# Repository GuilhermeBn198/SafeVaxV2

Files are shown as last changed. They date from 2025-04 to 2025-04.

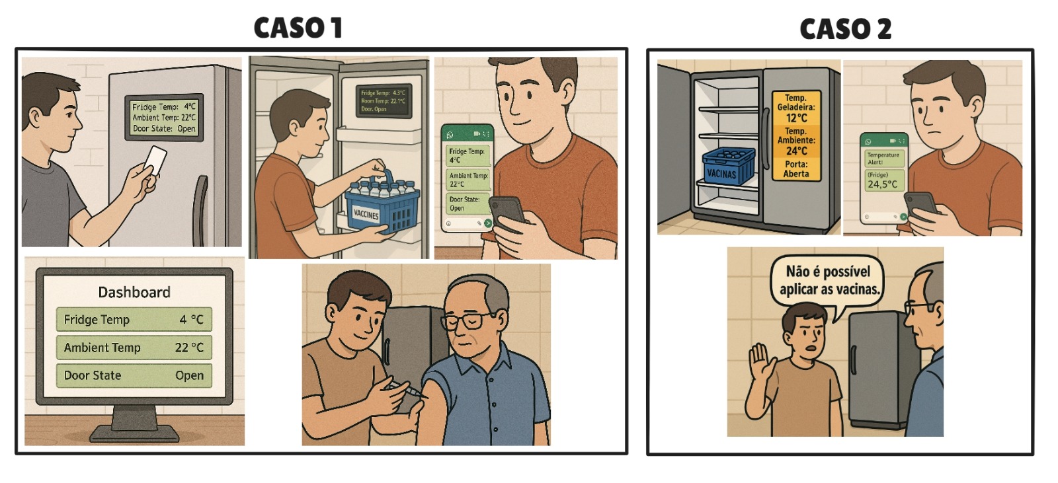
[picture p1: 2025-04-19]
Docs/Bigpicure_SafeVaxV2.jpeg

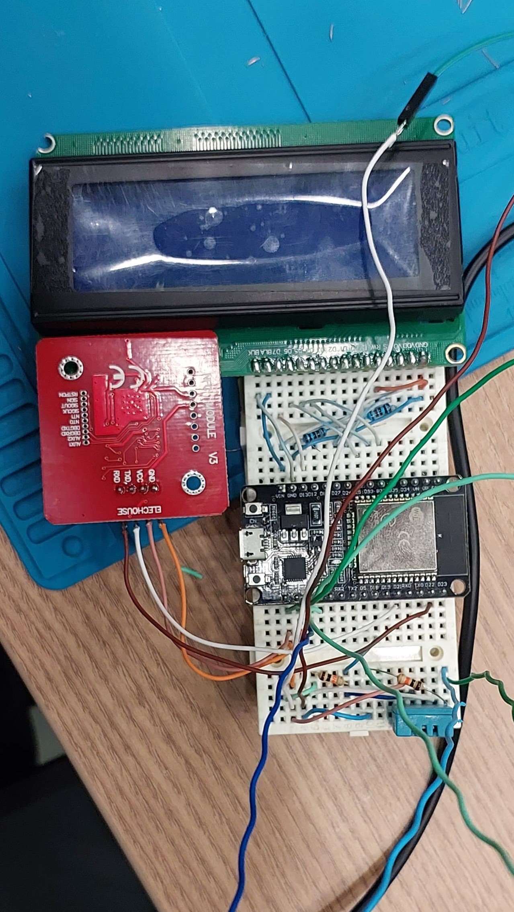
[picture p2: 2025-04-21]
Docs/imagens/prototipo pre-caixa.jpeg

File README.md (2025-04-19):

# SafeVax V2

O SafeVax é um sistema inovador voltado para o monitoramento e a segurança no armazenamento de vacinas em ambientes hospitalares. Desenvolvido para reduzir riscos e aumentar a eficiência no gerenciamento e administração de vacinas, o projeto utiliza sensores IoT (como DHT11 e RFID), compressão Huffman e criptografia AES para garantir que as condições ideais de conservação sejam sempre mantidas de forma segura e otimizada.

---

## Problema Abordado

O armazenamento adequado de vacinas é essencial para preservar sua eficácia e garantir a segurança dos pacientes. Em ambientes hospitalares, a violação das condições ideais — como a abertura frequente das portas dos refrigeradores e variações de temperatura — pode comprometer a qualidade dos insumos e, consequentemente, a saúde pública. Processos manuais de monitoramento estão sujeitos a falhas humanas, demandando uma solução automatizada, integrada e confiável.

---

## Solução Proposta

O SafeVax automatiza o monitoramento dos refrigeradores de vacinas através de:

- **Controle de Acesso:** Monitoramento da abertura e fechamento das portas do refrigerador, com registro detalhado dos acessos via sensor ultrassônico e RFID.  
- **Monitoramento de Temperatura:** Acompanhamento em tempo real da temperatura interna e externa (ambiente) com dois DHT11.  
- **Identificação via RFID:** Registro de quem acessa o refrigerador, possibilitando rastreabilidade e controle de acesso.  
- **Compressão de Dados (Huffman):** Redução do tamanho do payload JSON antes da transmissão, com árvore estática construída a partir do sampleAlphabet.  
- **Criptografia AES‑256‑CBC:** Proteção do payload comprimido usando chave de 256 bits e IV de 128 bits, garantindo confidencialidade em trânsito.  
- **Integração com Sistemas Hospitalares:** Sincronização de dados com plataformas de gestão de saúde para um monitoramento centralizado.  
- **Relatórios Automáticos & Alertas:** Geração de relatórios históricos e envio de alertas (via MQTT e WhatsApp) em caso de irregularidades.

### Melhorias e Funcionalidades Adicionais

- **Dashboard Interativo com Streamlit:** Consome as rotas HTTP do servidor Flask para visualização em tempo real e histórica.  
- **Segurança de Comunicação:**  
  - **HiveMQ TLS** para canal MQTT seguro.  
  - **AES‑256‑CBC** para criptografia de cada mensagem.  
- **Escalabilidade MQTT:** Cada ESP32 publica em `/centroDeVacinaXYZ/containerXYZ`, permitindo múltiplos containers.

---

## Credenciais e Parâmetros de Integração

| Item | Valor / Descrição |
|---|---|
| **Broker MQTT (HiveMQ)** | `cd8839ea5ec5423da3aaa6691e5183a5.s1.eu.hivemq.cloud:8883` (TLS) |
| **Username HiveMQ** | `hivemq.webclient.1734636778463` |
| **Password HiveMQ** | `EU<pO3F7x?S%wLk4#5ib` |
| **Tópico de Dados** | `/<centroDeVacinaXYZ>/<containerXYZ>` |
| **Tópico de Controle** | `esp32/control` |
| **Dicionário Huffman** | Gerado a partir do _sampleAlphabet_ (veja `PAYLOADS.md` para mapa completo `char → código binário`) |
| **Chave AES‑256 (hex)** | `A1B2C3D4E5F60718293A4B5C6D7E8F90112233445566778899AABBCCDDEEFF00` |
| **IV AES‑128 (hex)** | `00112233445566778899AABBCCDDEEFF` |

> **Nota:** em produção, o IV deve ser gerado aleatoriamente por mensagem e prefixado ao payload criptografado.

---

## Referências

- **Código-fonte ESP32:** integra DHT11 interno/externo, ultrassônico, RFID, LCD, Huffman e AES.  
- **Servidor Flask + PostgreSQL:** coleta dados MQTT, armazena em tabelas separadas (`containers` e `dados_monitoramento`).  
- **Dashboard Streamlit:** consome rotas HTTP e exibe gráficos e tabelas.  
- **PAYLOADS.md:** documentação detalhada de payload JSON, compressão e criptografia.  
  → [Veja em PAYLOADS.md](./PAYLOADS.md)

---

## Desenvolvedores

- **Guilherme Lucas Pereira Bernardo** – _Líder de Projeto & Desenvolvedor_ ~ @GuilhermeBn198
- **Vinícius Brito** – _Especialista em Hardware_ ~ @ViniKhael  
- **Ruan Oliveira** – _Desenvolvedor de Software e Especialista em Saúde_ ~ @rouancb  
- **Gabriel Guilherme** – _Engenheiro de Dados_ ~ @Bounded-Bytes  

Para contribuir ou entrar em contato, consulte as informações no repositório.

---

SafeVax V2 é um passo importante rumo a um sistema de armazenamento de vacinas mais seguro, eficiente e confiável, promovendo a saúde pública e a excelência na gestão hospitalar.

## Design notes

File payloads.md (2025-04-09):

# SafeVax ESP32 — Payloads, Compressão e Criptografia

## 1. Estrutura do Payload JSON

Cada mensagem, antes de compressão e criptografia, tem o formato:

```json
{
  "temperatura_interna": 7.25,
  "umidade_interna": 45.80,
  "temperatura_externa": 26.10,
  "umidade_externa": 55.20,
  "estado_porta": "Fechada",
  "usuario": "ab12cd34",
  "alarm_state": "OK",
  "motivo": "periodic"
}
```

## 2. Compressão Huffman

1. **Árvore estática**: gerada a partir do `sampleAlphabet`.
2. **Mapeamento**: cada caractere → código binário (ex.: `{`→`1010`, `}`→`1101`, etc.).
3. **Compressão**: substitui cada caractere pelo seu código.

```cpp
String compressed = huffmanCompress(jsonString);
```

## 3. Criptografia AES-256-CBC

1. **Pad PKCS#7** para múltiplos de 16 bytes.  
2. **Encriptação** com chave de 256 bits e IV de 128 bits:

   ```cpp
   String cipher = aes_encrypt_b64(compressed);
   ```

3. **Envio**: `client.publish(topic, cipher.c_str());`

## 4. Descriptografia e Descompressão

No ESP32 (callback) ou em outro AP:

1. **Base64 → bytes**  
2. **AES-256-CBC decrypt** → padded compressed  
3. **Remove pad** → compressed  
4. **Huffman decompress** → JSON original  

   ```cpp
   String decrypted = aes_decrypt_b64(cipherText);
   String json = huffmanDecompress(decrypted, huffmanTree);
   ```

## 5. Exemplo Completo

```text
JSON → Huffman → AES → Base64  → MQTT
          ↑             ↑
      Descomprime  Descriptografa
```

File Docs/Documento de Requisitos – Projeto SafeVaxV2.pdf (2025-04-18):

Documento de Requisitos – Projeto SafeVax V2

Introdução

O projeto SafeVax V2 tem como objetivo oferecer uma solução automatizada, segura e escalável para o monitoramento e a proteção no armazenamento de vacinas em ambientes hospitalares. Utilizando dispositivos IoT e uma arquitetura distribuída, o sistema garante que as condições ideais de conservação sejam mantidas, contribuindo para a segurança dos pacientes e a eficiência dos processos de gerenciamento.

Escopo

O sistema SafeVax V2 abrange as seguintes funcionalidades:

- Monitoramento em Tempo Real:
- Coleta de dados de temperatura e estado dos freezers por meio de sensores (ex.: DHT11 e sensores de abertura/fechamento de portas).
- Registro e Controle de Acessos:
- Registro dos acessos através de tecnologia RFID.
- Integração e Comunicação:
- Envio dos dados coletados, criptografados e compactados (usando Huffman), para um broker MQTT.
- Estruturação de tópicos MQTT que possibilitam a identificação individual de cada freezer e seus sensores.
- Processamento Centralizado:
- Um servidor Flask capta as informações do broker MQTT, descompacta e descriptografa os dados e os registra em um banco de dados PostgreSQL.
- O servidor Flask expõe os dados via API HTTP para consumo por outros módulos.
- Visualização e Notificações:
- Um dashboard interativo, desenvolvido com Streamlit, se conecta à API do servidor Flask para gerar gráficos, tabelas e relatórios históricos.

- Notificações de alerta no WhatsApp quando o acesso for “NÃO AUTORIZADO” e quando a temperatura for maior que a indicada pela OMS. (Entre 2º e 8º C)

Objetivos

- Garantir a eficácia das vacinas:
- Monitorar e manter as condições ideais de armazenamento por meio de medições precisas e automáticas.
- Melhorar a segurança:
- Registrar os acessos e identificar os responsáveis pela abertura dos refrigeradores utilizando RFID.
- Automatizar a gestão:
- Reduzir a dependência de processos manuais e minimizar erros humanos, utilizando comunicação via MQTT e processamento centralizado.
- Facilitar a análise dos dados:
- Disponibilizar informações de forma clara e interativa por meio de dashboards (Streamlit) e relatórios históricos.
- Assegurar a integridade e a segurança dos dados:
- Aplicar algoritmos de compactação (Huffman) e criptografia robusta em todas as etapas da comunicação entre os dispositivos IoT, o servidor e as interfaces de visualização e alerta.

Requisitos Funcionais

Monitoramento e Controle

- RF1: O sistema deverá monitorar a temperatura interna dos refrigeradores em tempo real utilizando o sensor DHT11.
- RF2: O sistema deverá registrar o estado (aberto/fechado) da porta dos containers através de um sensor de ultrassônico HC-SR04. O sensor ficará fixado na parte superior do container, voltado para a parte móvel da porta. Ao detectar uma alteração de distância – que indica a abertura ou fechamento da porta – o sensor informará o sistema imediatamente. Além disso, se a porta for aberta e não for identificada a presença de um cartão RFID dentro de 10 segundos, o sistema deverá emitir um alerta.

- RF3: O sistema deverá identificar e registrar os usuários que acessam os freezers utilizando tecnologia RFID.

Integração e Comunicação

- RF5: O sistema deverá enviar os dados coletados, devidamente criptografados e compactados (usando o algoritmo de Huffman), para um broker MQTT.
- RF6: O sistema deverá utilizar uma estrutura de tópicos MQTT para identificar individualmente cada freezer e seus respectivos sensores.
- RF7: Um servidor Flask deverá captar os dados enviados via MQTT, descompactá-los e descriptografá-los, registrando as informações em um banco de dados SQLite.
- RF8: O servidor Flask deverá disponibilizar os dados processados via API HTTP para consumo por outras interfaces do sistema.

Alertas e Notificações

- RF9: O sistema deverá enviar notificações automáticas via WhatsApp aos gestores em casos de irregularidades.

Visualização de Dados

- RF11: Um dashboard interativo, utilizando a ferramenta Streamlit, deverá ser disponibilizado para a visualização dos dados coletados de forma clara e legível.
- RF12: O dashboard deverá apresentar gráficos, tabelas e relatórios históricos para auxiliar na análise e tomada de decisões.

Requisitos Não Funcionais

Performance

- RNF1: O sistema deverá realizar a coleta e transmissão dos dados com baixa latência, garantindo atualizações em tempo real.
- RNF2: A compactação dos dados deverá reduzir significativamente o volume de informações transmitidas, sem comprometer a integridade dos dados.

Segurança

- RNF3: A comunicação entre os dispositivos IoT, o broker MQTT, o servidor Flask deverá ser protegida por criptografia robusta.
- RNF4: O acesso ao dashboard e aos dados deverá ser controlado por autenticação e autorização.

Usabilidade

- RNF5: O dashboard desenvolvido em Streamlit deverá oferecer uma experiência de usuário clara, com design responsivo.

Escalabilidade e Manutenção

- RNF6: A arquitetura do sistema deverá ser modular e escalável.
- RNF7: O código deverá ser documentado e seguir boas práticas de desenvolvimento.

Requisitos de Integração e Melhoria

- RM1: Implementar algoritmos de compactação de dados (mínimo dois), utilizando o algoritmo de Huffman.
- RM2: Implementar um algoritmo de criptografia robusto.
- RM3: Desenvolver um dashboard interativo utilizando Streamlit.
- RM4: Implementar um mecanismo de cadastro e gerenciamento de múltiplos freezers, utilizando tópicos MQTT estruturados.

Considerações Finais

O projeto SafeVax V2 visa transformar o monitoramento e a segurança no armazenamento de vacinas em ambientes hospitalares através de uma abordagem integrada que alta tecnologia IoT, segurança de dados e interfaces amigáveis para o usuário. Este documento de requisitos servirá de base para o desenvolvimento e a validação do sistema, garantindo que todas as funcionalidades essenciais e melhorias sejam implementadas de acordo com as necessidades dos stakeholders e as melhores práticas de engenharia.

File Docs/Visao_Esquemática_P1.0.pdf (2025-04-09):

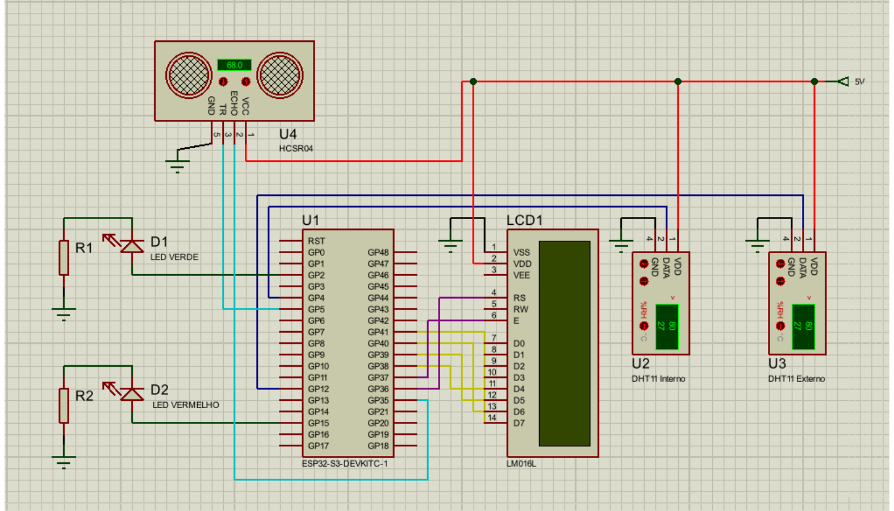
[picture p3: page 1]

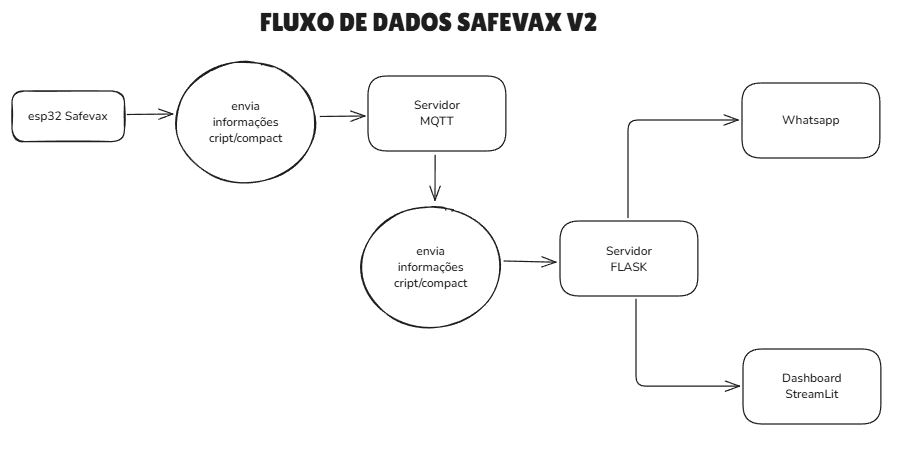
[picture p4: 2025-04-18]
Docs/Fluxo_de_Dados_SafeVaxV2.jpeg

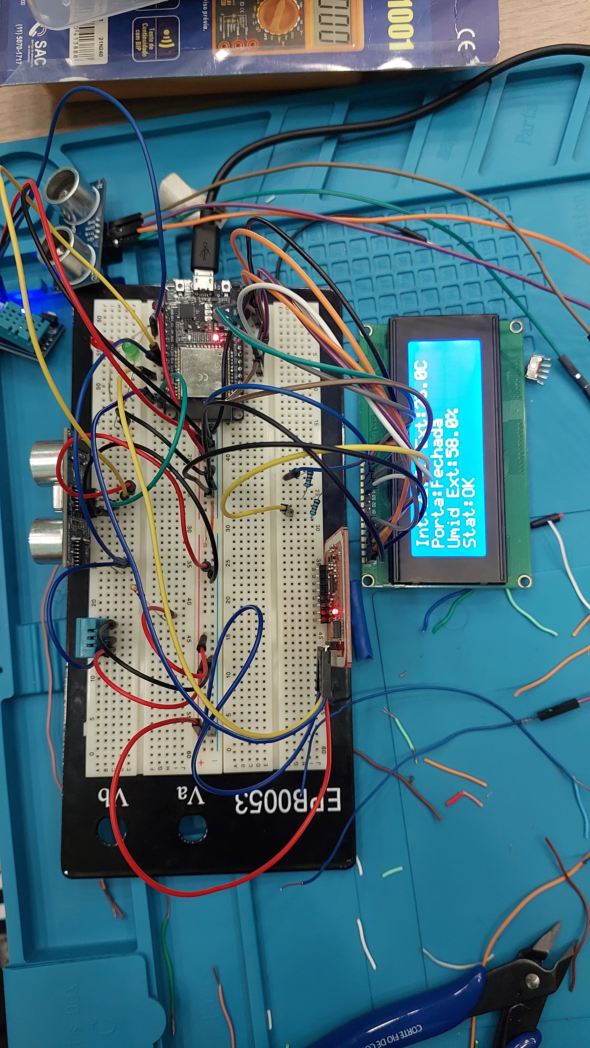
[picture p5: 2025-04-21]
Docs/imagens/prototipo 1.jpeg

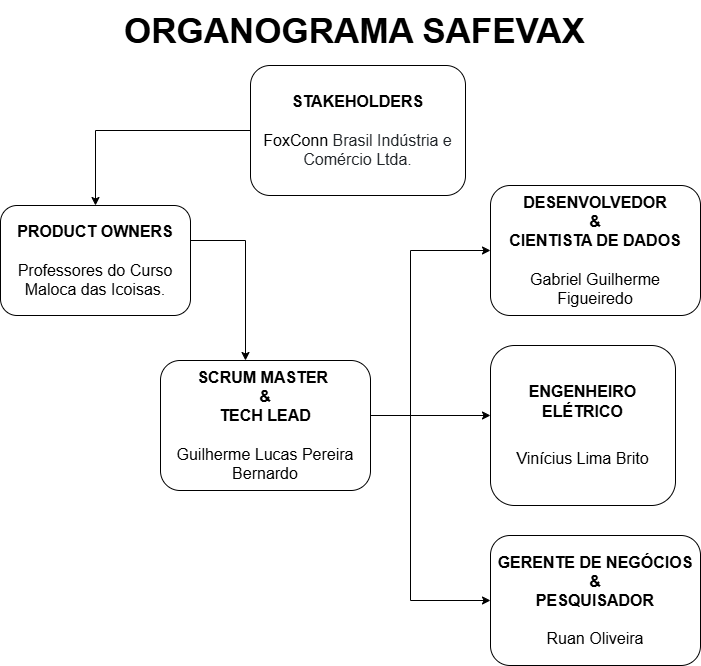
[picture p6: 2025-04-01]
Docs/Organograma-SafeVaxV2.drawio.png

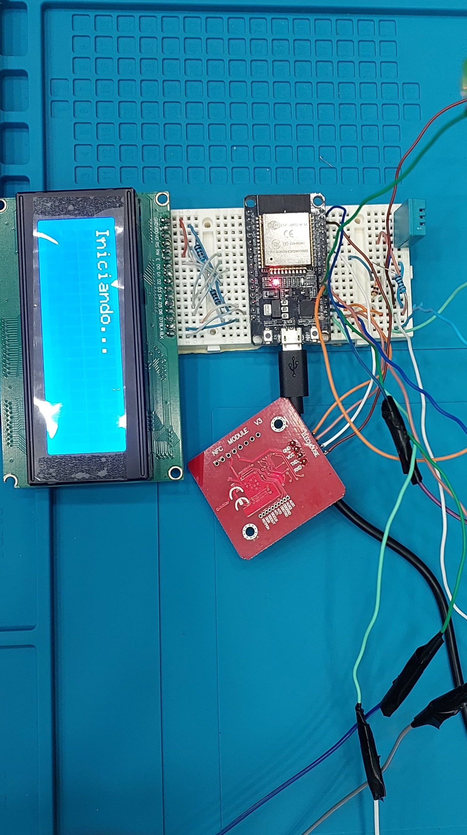
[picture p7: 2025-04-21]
Docs/imagens/prototipo pre-caixa-2.jpeg

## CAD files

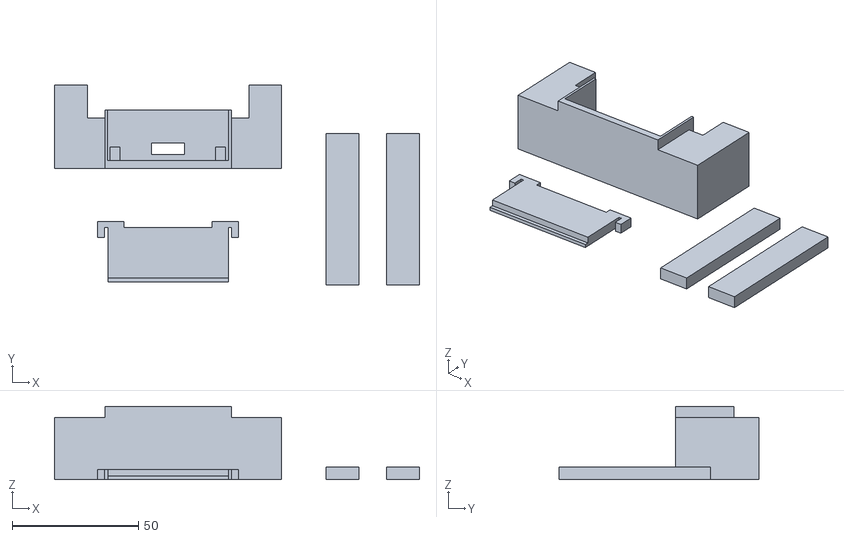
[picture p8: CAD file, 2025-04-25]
3d_printing/Sensor-ultrassonico_Safevax_imprimir.stl
144.6 x 79.3 x 29.0

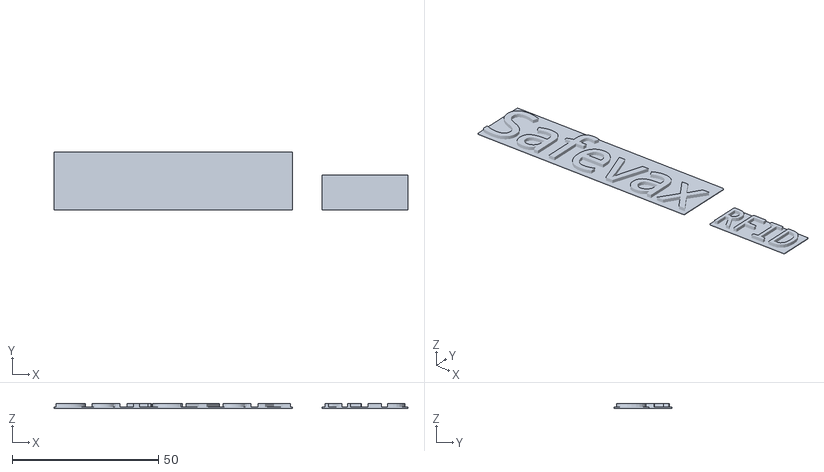
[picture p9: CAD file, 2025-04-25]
3d_printing/Letras_Caixa_imprimir.stl
121.2 x 20.0 x 1.60

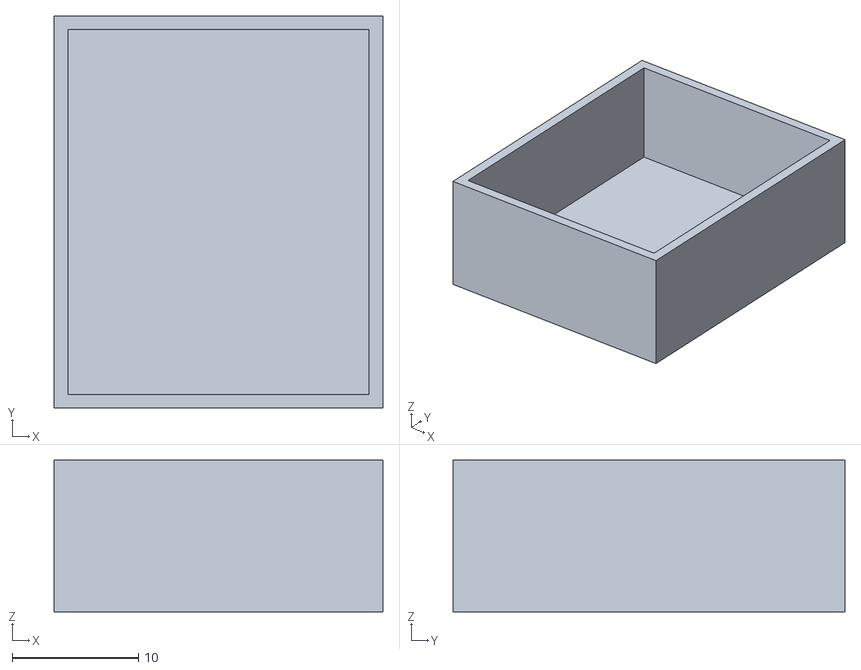
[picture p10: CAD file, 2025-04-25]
3d_printing/DHT_Interno_imprimir.stl
26.0 x 31.0 x 12.0

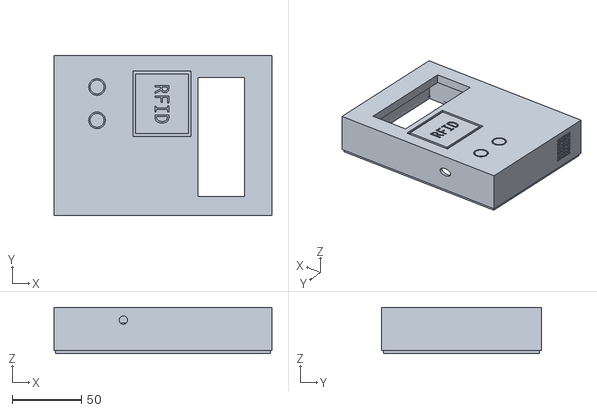
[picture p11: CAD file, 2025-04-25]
3d_printing/Topo_Safevax_imprimir.stl
157.0 x 115.0 x 33.4

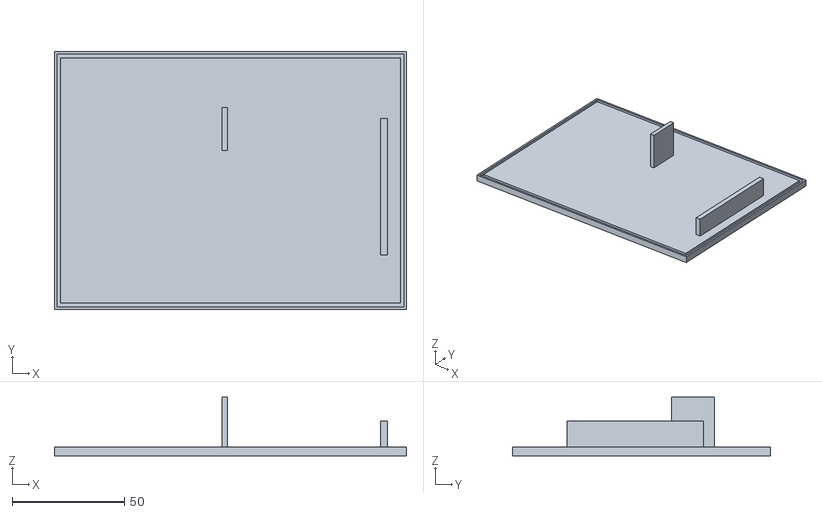
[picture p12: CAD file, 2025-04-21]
3d_printing/Base_Safevax_imprimir.stl
157.0 x 115.0 x 26.2

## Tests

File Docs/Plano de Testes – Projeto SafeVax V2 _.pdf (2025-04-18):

Plano de Testes – Projeto SafeVax V2

### 1. Introdução

Este documento descreve o plano de testes para o projeto SafeVax V2, visando validar que o sistema atende aos requisitos funcionais, não funcionais e de integração. O objetivo é garantir que todas as funcionalidades – desde a coleta e transmissão dos dados dos freezers até a visualização e notificação – operem de forma segura, eficiente e integrada.

### 2. Objetivos dos Testes

- Verificação Funcional: Garantir que cada requisito funcional seja implementado corretamente e opere conforme esperado.
- Validação da Integração: Assegurar que os diferentes módulos do sistema (dispositivos IoT, broker MQTT, servidor Flask, banco de dados, dashboard Streamlit) se comuniquem e interajam corretamente.
- Avaliação da Segurança e Desempenho: Testar a eficácia dos algoritmos de compactação (Huffman) e criptografia, bem como a latência na transmissão dos dados.
- Testes de Usabilidade: Verificar a interface e a experiência do usuário no dashboard interativo em Streamlit e com as notificações.
- Testes Manuais e Unitários: Enquanto os módulos do ESP32 serão validados via testes manuais in loco, os testes unitários serão aplicados no Streamlit.

### 3. Escopo dos Testes

3.1 - Componentes a Serem Testados

- Dispositivos IoT e Comunicação via MQTT:
- Sensores de temperatura (DHT11).
- Sensores de estado da porta do container, utilizando sensor de luz infravermelho PIR, instalado na parte superior do container e voltado para a parte móvel da porta.
- Módulo RFID para identificação de acessos.
- Envio dos dados (compactados e criptografados) via MQTT.

- Servidor Flask e Integração com Banco de Dados:
- Captação dos dados via MQTT.
- Processamento: descompactação (Huffman), descriptografia e registro dos dados em banco (SQLite ou PostgreSQL, conforme a versão adotada).
- Exposição dos dados via API HTTP.
- Interface de Visualização e Notificações:
- Dashboard interativo desenvolvido com Streamlit.
- Notificações no WhatsApp para recebimento dos dados, emissão de alertas.

Componentes Excluídos dos Testes

- Testes unitários e de integração não serão aplicados aos módulos do ESP32, que serão validados via testes manuais in loco.

### 4. Estratégia de Testes

4.1 - Tipos de Testes

- Testes Funcionais (Manuais):
- Funcionamento dos sensores (temperatura e sensor PIR para estado da porta).
- Leitura e registro dos acessos via RFID.
- Envio e recepção dos dados via MQTT.
- Processamento no servidor Flask (descompactação, descriptografia e registro dos dados).
- Testes de Integração (Manuais):
- Dispositivos IoT → Broker MQTT → Servidor Flask → API HTTP.
- Integração entre o servidor e o dashboard (Streamlit).
- Testes Unitários (Automatizados):

- Módulos do dashboard em Streamlit:

■ Validação dos métodos de descriptografia e descompactação. ■ Verificação da lógica de exibição e manipulação de dados.
■ Testes de notificação e alerta no WhatsApp.
- Testes de Segurança:
- Robustez da criptografia aplicada e integridade dos dados durante a transmissão.
- Testes de Performance:
- Medir a latência na transmissão dos dados e a eficácia da compactação, garantindo comunicação em tempo real com baixa latência.

4.2 - Ferramentas de Teste

- Ambiente de Teste Manual:
- Equipamentos com ESP32, sensores (DHT11 e sensor PIR), módulo RFID e broker MQTT configurado.
- Ambiente de Teste Automatizado:
- Frameworks de testes para Streamlit (Python unittest/pytest).
- Ferramentas de Monitoramento:
- Logs e analisadores de pacotes (ex.: Wireshark) para validar a criptografia e a integridade dos dados.

### 5. Casos de Teste

5.1 - Testes Funcionais

- TF-01: Monitoramento de Temperatura
- Objetivo: Verificar se o sensor DHT11 coleta e envia a temperatura em tempo real.
- Procedimento:

1. Simular variações de temperatura no ambiente do freezer.
2. Verificar a exibição dos dados enviados via MQTT.
- Resultado Esperado: Dados precisos e atualizados em tempo real.
- TF-02: Registro de Estado da Porta do Container
- Objetivo: Confirmar que o sensor de luz infravermelho PIR registra corretamente o estado (aberto/fechado) da porta do container.
- Procedimento:
1. Simular a abertura e fechamento da porta do container.
2. Observar se o sensor PIR detecta a alteração de estado imediatamente e se essa informação é enviada ao sistema.
- Resultado Esperado: Cada mudança de estado é registrada e transmitida instantaneamente.
- TF-03: Emissão de Alerta por Ausência de RFID
- Objetivo: Validar que, ao abrir a porta do container, se nenhum cartão RFID for identificado em até 10 segundos, o sistema emite um alerta.
- Procedimento:
1. Abrir a porta do container.
2. Não apresentar nenhum cartão RFID ao leitor durante 10 segundos.
3. Verificar se o sistema emite o alerta conforme especificado.
- Resultado Esperado: Alerta emitido imediatamente após o período de 10 segundos sem identificação de RFID.
- TF-04: Identificação via RFID
- Objetivo: Validar o registro de acesso dos usuários por meio do RFID.
- Procedimento:

1. Aproximar um cartão RFID do leitor.
2. Verificar se o acesso é registrado com os dados corretos.
- Resultado Esperado: A identificação do usuário é capturada e enviada corretamente.
- TF-05: Envio de Dados via MQTT
- Objetivo: Confirmar que os dados são compactados, criptografados e enviados ao broker MQTT.
- Procedimento:
1. Verificar os dados enviados a partir dos freezers utilizando um analisador de pacotes.
- Resultado Esperado: Dados enviados no formato esperado, compactados e criptografados.

### 5.2 Testes de Integração

- TI-01: Integração do Servidor Flask
- Objetivo: Verificar a recepção dos dados pelo servidor Flask e seu processamento (descompactação e descriptografia).
- Procedimento:
1. Enviar dados via MQTT a partir dos dispositivos.
2. Confirmar que o servidor Flask processa e armazena os dados no banco.
- Resultado Esperado: Dados corretamente registrados e disponíveis via API HTTP.
- TI-02: Integração do Dashboard (Streamlit)
- Objetivo: Validar a exibição dos dados no dashboard interativo.
- Procedimento:
1. Conectar o dashboard à API do servidor Flask.

2. Verificar a atualização em tempo real dos gráficos e tabelas.
- Resultado Esperado: Dados apresentados de forma clara e interativa.
- TI-03: Integração das notificações
- Objetivo: Testar o consumo dos dados (criptografados e compactados) e o envio de alertas.
- Procedimento:
1. Simular condições críticas (ex.: temperatura elevada ou porta aberta sem RFID).
2. Verificar a recepção dos dados no WhatsApp e a emissão dos alertas.
- Resultado Esperado: Notificações enviadas corretamente aos gestores.

### 5.3 Testes de Segurança

- TS-01: Validação da Criptografia
- Objetivo: Confirmar que os dados são criptografados durante a transmissão.
- Procedimento:
1. Utilizar ferramentas de análise de pacotes para interceptar a comunicação.
2. Verificar se os dados estão protegidos.
- Resultado Esperado: Nenhum dado em texto claro é visível.
- TS-02: Teste de Integridade dos Dados
- Objetivo: Verificar se os dados mantêm sua integridade após a compactação e descompactação.
- Procedimento:
1. Comparar os dados antes e depois do processo.
- Resultado Esperado: Os dados permanecem íntegros e sem perdas.

### 5.4 Testes de Performance

- TP-01: Latência na Transmissão
- Objetivo: Medir o tempo entre a coleta dos dados e sua disponibilidade via API.
- Procedimento:
1. Realizar medições em diferentes condições de rede.
- Resultado Esperado: Latência dentro dos parâmetros estabelecidos para atualizações em tempo real.

### 5.5 Testes Unitários (Criptografia e Streamlit)

- TU-01: Testes de Descriptografia e Descompactação
- Objetivo: Validar as funções de descriptografia e descompactação dos dados.
- Procedimento:
1. Executar testes automatizados utilizando o framework de testes.
- Resultado Esperado: Funções retornam os dados corretamente processados.
- TU-02: Testes dos Componentes do Dashboard (Streamlit)
- Objetivo: Verificar que os componentes do dashboard (gráficos, tabelas, etc.) processam e exibem os dados conforme esperado.
- Procedimento:
1. Utilizar pytest ou outro framework para testar os componentes.
- Resultado Esperado: Componentes apresentam os dados de forma correta e responsiva.

### 6. Cronograma e Ambiente de Teste

- Ambiente de Teste Manual:

- Equipamentos com ESP32, sensores (DHT11 e PIR), módulo RFID e freezers em ambiente controlado.
- Broker MQTT configurado para simulação do fluxo completo.
- Ambiente de Teste Automatizado:
- Configuração de testes unitários para o Streamlit em ambiente de desenvolvimento.
- Cronograma:
- Testes Funcionais e de Integração: Durante a implementação e após a integração de cada módulo.
- Testes Unitários: Após a implementação dos módulos críticos no Streamlit.
- Testes de Performance e Segurança: Durante a fase de integração e antes da implantação final.

### 7. Critérios de Aceitação

- Funcionalidade: Todos os requisitos funcionais e de integração (incluindo os novos testes para o sensor PIR e a verificação do alerta por ausência de RFID) devem ser atendidos conforme os resultados dos testes.
- Segurança: A comunicação deve estar criptografada e os dados devem manter sua integridade durante os processos de compactação/descompactação.
- Performance: A latência do sistema deve permitir atualizações em tempo real.
- Usabilidade: As interfaces das notificações e do dashboard devem ser intuitivas e responsivas, garantindo uma boa experiência ao usuário.

### 8. Conclusão

Este plano de testes tem o intuito de assegurar que o projeto SafeVax V2 opere de forma integrada, segura e eficiente, cumprindo todos os requisitos definidos – incluindo a nova abordagem para o monitoramento do estado da porta do container via sensor PIR e a emissão de alertas na ausência de identificação RFID dentro de 10 segundos. As etapas de testes manuais, unitários e de integração garantirão a qualidade e robustez do sistema antes da implantação em ambiente real. Este documento será atualizado conforme novas funcionalidades e requisitos forem incorporados ao projeto.

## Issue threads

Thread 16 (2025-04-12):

História 10: Desenvolver a apresentação do SafeVax V2

ViniKhael, 2025-04-12:
Objetivo: confeccionar slides para apresentação final

ViniKhael, 2025-04-12:
link para edição

[slides](https://www.canva.com/design/DAGkXQlZIMw/yxwt_RUENYFcpbU0UVuHzg/edit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)

ViniKhael, 2025-04-25:
finalizado com ultimo commit da task sendo

> Commit 7535cfe

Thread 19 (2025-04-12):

História 4: Desenvolvimento do Aplicativo Mobile em Flutter

GuilhermeBn198, 2025-04-12:
Objetivo: Criar um aplicativo mobile que consome os dados do servidor MQTT (ou da API do Flask) e exibe alertas e notificações em tempo real.

- [ ] Task 4.1: Criar a estrutura inicial do aplicativo em Flutter.

- [ ] Task 4.2: Implementar a conexão com o servidor MQTT ou com a API HTTP para receber dados.

- [ ] Task 4.3: Desenvolver a funcionalidade para descriptografar e descompactar os dados recebidos.

- [ ] Task 4.4: Implementar notificações e alertas baseados nos dados críticos (ex.: temperatura acima do limite).

- [ ] Task 4.5: Desenvolver e executar testes unitários nos módulos críticos do aplicativo.

GuilhermeBn198, 2025-04-12:
Decidimos por encerrar o desenvolvimento do aplicativo e passar a gerar notificações diretamente pelo servidor Flask, através de sms, whatsapp api ou EMAIL

Closed 2025-04-12.

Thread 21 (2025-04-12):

História 6: Cadastro e Gerenciamento de Múltiplos Freezers

GuilhermeBn198, 2025-04-12:
Objetivo: Desenvolver e implementar a estratégia para cadastrar e gerenciar múltiplos freezers, utilizando tópicos MQTT e mensagens retidas.

- [ ] Task 6.1: Definir e implementar a estrutura dos tópicos MQTT para freezers e sensores.

- [ ] Task 6.2: Criar um mecanismo de cadastro (por exemplo, utilizando mensagens MQTT retidas ou um arquivo de configuração) para registrar os freezers e seus sensores.

- [ ] Task 6.3: Implementar a lógica no ESP32 para associar cada sensor a um freezer específico.

- [ ] Task 6.4: Validar a integração e a distinção dos dados entre os freezers através de testes manuais.

- [ ] Task 6.5: Atualizar a documentação com o novo fluxo de cadastro e gerenciamento de freezers.

ViniKhael, 2025-04-25:
fechado com ultimo commit relacionado ao assunto:

> sendo Commit 41b83aa

> Dashboard finalizado podendo utilizar dados de diferentes freezers [https://safevaxv2-e3nuk9n9uzugpcmk6w2gep.streamlit.app/](Dashboard Safevax V2)

Closed 2025-04-25.

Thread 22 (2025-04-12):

História 3: Desenvolvimento do Servidor Flask e Integração com Banco SQLite

GuilhermeBn198, 2025-04-12:
Objetivo: Criar um servidor Flask que capta dados do MQTT, descompacta e descriptografa as informações e as registra em um banco SQLite.

- [x] Task 3.1: Desenvolver o servidor Flask para se conectar ao broker MQTT e receber os dados.

- [x] Task 3.2: Implementar a lógica para descompactar (Huffman) e descriptografar os dados recebidos.

- [x] Task 3.3: Registrar os dados processados em um banco de dados SQLite.

- [x] Task 3.4: Expor uma API HTTP que disponibilize os dados criptografados e compactados para o consumo pelo Streamlit e Flutter.

ViniKhael, 2025-04-25:
História finalizada sendo o ultimo commit relacionado:

> Commit 98f3260

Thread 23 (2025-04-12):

História 5: Desenvolvimento do Dashboard Interativo com Streamlit

GuilhermeBn198, 2025-04-12:
Objetivo: Criar um dashboard interativo que consome dados da API do Flask e apresenta gráficos e relatórios para análise.

- [x] Task 5.1: Criar o layout básico do dashboard utilizando Streamlit.

- [ ] Task 5.2: Implementar a conexão com a API do Flask para receber os dados.

- [x] Task 5.3: Desenvolver gráficos, tabelas e relatórios que apresentem os dados de forma clara.

- [x] Task 5.4: Desenvolver e executar testes unitários para os componentes do dashboard.

ViniKhael, 2025-04-25:
história fechada com ultimo commit relacionado sendo:

> Commit 41b83aa

Closed 2025-04-25.

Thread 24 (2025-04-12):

História 7: Projeto de Modelagem 3D e Layout do Hardware

GuilhermeBn198, 2025-04-12:
**Objetivo:** Definir e implementar a disposição física dos dispositivos e eletrônicos no freezer de vacinas, utilizando uma impressora 3D para a criação de suportes e peças customizadas que garantam a integridade dos componentes e a eficiência do monitoramento.

### Abordagem e Considerações Técnicas
**ESP32:**
Recomenda-se que o ESP32 seja posicionado fora do freezer. Essa localização evita problemas relacionados à umidade e condensação, além de facilitar a manutenção e o acesso para eventuais atualizações.

**Sensor DHT11:**
O sensor deve estar localizado dentro do freezer para medir com precisão a temperatura interna. Entretanto, ele pode ser fixado em um suporte impresso em 3D que garanta sua estabilidade e a proteção contra impactos, sem interferir na circulação do ar.

**Módulo RFID:**
O módulo de RFID pode ser posicionado junto ao ESP32, fora do freezer, ou em uma área de interface com o usuário (próximo à porta) onde o cartão possa ser lido sem expor o sensor a condições adversas de baixa temperatura. Isso possibilita uma identificação rápida e evita que o módulo fique em ambiente de difícil acesso para manutenção.

**Relé Eletrônico para Controle de Containeres:**
O relé, responsável pela operação dos containeres, pode ser instalado em uma posição estratégica na parte externa do freezer, acoplado a um mecanismo (como atuadores ou servos) que opere a abertura/fechamento. Um suporte ou caixa customizada via impressão 3D pode proteger o relé e organizar as conexões, garantindo que a integração com os containeres seja segura e confiável.

## **Tasks**

ViniKhael, 2025-04-25:
Historia finalizada pelo ultimo commit relacionado:

> Commit 00a357f

Closed 2025-04-25.

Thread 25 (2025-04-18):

História 11: Pivotagem de Solução

ViniKhael, 2025-04-18:
Retirada de aplicativo Flutter e substituição por API de mensageria via aplicativo Whatsapp.

- [x] Task 11.1: Alterar documento de requisitos
- [x] Task 11.2: Alterar documento de testes
- [x] Task 11.3: Alterar README
- [x] Task 11.4: Mudar o BigPicture do projeto
- [x] Task 11.5: Modificar o fluxograma de dados

Closed 2025-04-18.

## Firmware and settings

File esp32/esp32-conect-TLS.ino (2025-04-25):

#include <WiFi.h>
#include <WiFiClientSecure.h>
#include <PubSubClient.h>
#include <DHT.h>
#include <SPI.h>
#include <time.h>
#include <Adafruit_PN532.h>
#include <LiquidCrystal.h>
#include <Arduino.h>
#include <map>
#include <queue>

// ----- CERTIFICADOS TLS -----
const char* hivemq_root_ca = \
"-----BEGIN CERTIFICATE-----\n" \
"MIIFBjCCAu6gAwIBAgIRAIp9PhPWLzDvI4a9KQdrNPgwDQYJKoZIhvcNAQELBQAwTzELMAkGA1UEBhMCVVMxKTAnBgNVBAoTIEludGVybmV0IFNlY3VyaXR5IFJlc2VhcmNoIEdyb3VwMRUwEwYDVQQDEwxJU1JHIFJvb3QgWDEwHhcNMjQwMzEzMDAwMDAwWhcNMjcwMzEyMjM1OTU5WjAzMQswCQYDVQQGEwJVUzEWMBQGA1UEChMNTGV0J3MgRW5jcnlwdDEMMAoGA1UEAxMDUjExMIIBIjANBgkqhkiG9w0BAQEFAAOCAQ8AMIIBCgKCAQEAuoe8XBsAOcvKCs3UZxD5ATylTqVhyybKUvsVAbe5KPUoHu0nsyQYOWcJDAjs4DqwO3cOvfPlOVRBDE6uQdaZdN5R2+97/1i9qLcT9t4x1fJyyXJqC4N0lZxGAGQUmfOx2SLZzaiSqhwmej/+71gFewiVgdtxD4774zEJuwm+UE1fj5F2PVqdnoPy6cRms+EGZkNIGIBloDcYmpuEMpexsr3E+BUAnSeI++JjF5ZsmydnS8TbKF5pwnnwSVzgJFDhxLyhBax7QG0AtMJBP6dYuC/FXJuluwme8f7rsIU5/agK70XEeOtlKsLPXzze41xNG/cLJyuqC0J3U095ah2H2QIDAQABo4H4MIH1MA4GA1UdDwEB/wQEAwIBhjAdBgNVHSUEFjAUBggrBgEFBQcDAgYIKwYBBQUHAwEwEgYDVR0TAQH/BAgwBgEB/wIBADAdBgNVHQ4EFgQUxc9GpOr0w8B6bJXELbBeki8m47kwHwYDVR0jBBgwFoAUebRZ5nu25eQBc4AIiMgaWPbpm24wMgYIKwYBBQUHAQEEJjAkMCIGCCsGAQUFBzAChhZodHRwOi8veDEuaS5sZW5jci5vcmcvMBMGA1UdIAQMMAowCAYGZ4EMAQIBMCcGA1UdHwQgMB4wHKAaoBiGFmh0dHA6Ly94MS5jLmxlbmNyLm9yZy8wDQYJKoZIhvcNAQELBQADggIBAE7iiV0KAxyQOND1H/lxXPjDj7I3iHpvsCUf7b632IYGjukJhM1yv4Hz/MrPU0jtvfZpQtSlET41yBOykh0FX+ou1Nj4ScOt9ZmWnO8m2OG0JAtIIE3801S0qcYhyOE2G/93ZCkXufBL713qzXnQv5C/viOykNpKqUgxdKlEC+Hi9i2DcaR1e9KUwQUZRhy5j/PEdEglKg3l9dtD4tuTm7kZtB8v32oOjzHTYw+7KdzdZiw/sBtnUfhBPORNuay4pJxmY/WrhSMdzFO2q3Gu3MUBcdo27goYKjL9CTF8j/Zz55yctUoVaneCWs/ajUX+HypkBTA+c8LGDLnWO2NKq0YD/pnARkAnYGPfUDoHR9gVSp/qRx+ZWghiDLZsMwhN1zjtSC0uBWiugF3vTNzYIEFfaPG7Ws3jDrAMMYebQ95JQ+HIBD/RPBuHRTBpqKlyDnkSHDHYPiNX3adPoPAcgdF3H2/W0rmoswMWgTlLn1Wu0mrks7/qpdWfS6PJ1jty80r2VKsM/Dj3YIDfbjXKdaFU5C+8bhfJGqU3taKauuz0wHVGT3eo6FlWkWYtbt4pgdamlwVeZEW+LM7qZEJEsMNPrfC03APKmZsJgpWCDWOKZvkZcvjVuYkQ4omYCTX5ohy+knMjdOmdH9c7SpqEWBDC86fiNex+O0XOMEZSa8DA" \
"-----END CERTIFICATE-----\n";

// --- Huffman Estático ---
const String HUFFMAN_DICT_VERSION = "v2";
const std::map<char, String> huffmanCodes = {
  {' ', String("110100")},
  {'!', String("1111111101")},
  {'"', String("000")},
  {'#', String("111111101")},
  {'$', String("11111111001")},
  {'%', String("111111011")},
  {'&', String("111111010")},
  {'(', String("111111111")},
  {')', String("1111111000")},
  {'*', String("111111110")},
  {'+', String("11111110")},
  {',', String("0011")},
  {'-', String("11111101")},
  {'.', String("01101")},
  {'/', String("11111111")},
  {'0', String("00011")},
  {'1', String("00100")},
  {'2', String("00101")},
  {'3', String("00110")},
  {'4', String("00111")},
  {'5', String("01000")},
  {'6', String("01001")},
  {'7', String("01010")},
  {'8', String("01011")},
  {'9', String("01100")},
  {':', String("0010")},
  {';', String("1111111011")},
  {'<', String("1111111001")},
  {'=', String("111111001")},
  {'>', String("1111111010")},
  {'?', String("1111111100")},
  {'@', String("111111100")},
  {'A', String("11111")},
  {'B', String("111100")},
  {'C', String("11101")},
  {'D', String("00010")},
  {'E', String("01110")},
  {'F', String("11110")},
  {'G', String("111101")},
  {'H', String("111110")},
  {'I', String("11001")},
  {'J', String("111111")},
  {'K', String("11000")},
  {'L', String("00000")},
  {'M', String("110011")},
  {'N', String("1111000")},
  {'O', String("10111")},
  {'P', String("1111001")},
  {'Q', String("1111010")},
  {'R', String("00001")},
  {'S', String("1111011")},
  {'T', String("110001")},
  {'U', String("110010")},
  {'V', String("1111100")},
  {'W', String("1111101")},
  {'X', String("1111110")},
  {'Y', String("1111111")},
  {'Z', String("11111000")},
  {'[', String("11111011")},
  {'\\', String("111111000")},
  {']', String("11111100")},
  {'^', String("11111111000")},
  {'_', String("11100")},
  {'a', String("0100")},
  {'b', String("10101")},
  {'c', String("01111")},
  {'d', String("1100")},
  {'e', String("0101")},
  {'f', String("110101")},
  {'g', String("10011")},
  {'h', String("10001")},
  {'i', String("0110")},
  {'j', String("110110")},
  {'k', String("10110")},
  {'l', String("10100")},
  {'m', String("1010")},
  {'n', String("10000")},
  {'o', String("0111")},
  {'p', String("11010")},
  {'q', String("110111")},
  {'r', String("1000")},
  {'s', String("11011")},
  {'t', String("1001")},
  {'u', String("1011")},
  {'v', String("10010")},
  {'w', String("111000")},
  {'x', String("111001")},
  {'y', String("111010")},
  {'z', String("111011")},
  {'{', String("11111001")},
  {'|', String("1111111110")},
  {'}', String("11111010")},
  {'~', String("1111111111")},
  {'$', String("11111111001")}
};

// --------------------------------------------------------------------------------
// PINOS E CONSTANTES
// --------------------------------------------------------------------------------
const int DHT_PIN_IN      = 4;
const int DHT_TYPE        = DHT11;
DHT dht_in(DHT_PIN_IN, DHT_TYPE);
const int DHT_PIN_EXT     = 18;
DHT dht_ext(DHT_PIN_EXT, DHT_TYPE);
const int TRIG_PIN        = 5;
const int ECHO_PIN        = 23;
const int LED_OK_PIN      = 2;
const int LED_ALERT_PIN   = 15;
const int SDA_PIN         = 21;
const int SCL_PIN         = 22;
Adafruit_PN532 nfc(SDA_PIN, SCL_PIN);
const int LCD_RS = 26, LCD_E = 27, LCD_D4 = 33, LCD_D5 = 32, LCD_D6 = 25, LCD_D7 = 13;
LiquidCrystal lcd(LCD_RS, LCD_E, LCD_D4, LCD_D5, LCD_D6, LCD_D7);

float THRESHOLD_TEMP       = 25.5;
unsigned long tempAboveStart = 0;
const unsigned long PERIODIC_SEND_INTERVAL = 60000;
const unsigned long GREEN_BLINK_INTERVAL   = 5000;
const unsigned long RED_BLINK_INTERVAL     = 1000;
const unsigned long UNAUTH_WINDOW_BEFORE   = 60000;
const unsigned long TEMP_ALERT_DURATION    = 10000;
const float distancia_limite = 7.0;

String centro    = "centroDeVacinaXYZ";
String container = "containerXYZ";
String mqtt_topic = "/" + centro + "/" + container;
const char* control_topic = "esp32/control";

const char* ssid     = "Starlink_CIT";
const char* password = "Ufrr@2024Cit";
const char* mqtt_server   = "6ef5d17c52994de69c847b10011cad30.s1.eu.hivemq.cloud";
const int   mqtt_port     = 8883;
const char* mqtt_username = "hivemq.webclient.1745085086443";
const char* mqtt_password = "1mI3:&xakvOCg*T$4JP7";

WiFiClientSecure espClient;
PubSubClient client(espClient);

unsigned long lastPeriodicSend = 0, lastGreenBlink = 0, lastRedBlink = 0;
String usuarioAtual = "desconhecido";
bool doorOpen = false, alarmState = false;
unsigned long lastRFIDTime = 0;
#define TEMP_HISTORY_SIZE 10
float tempHistory[TEMP_HISTORY_SIZE] = {0};
int tempIndex = 0;
bool avgAlertActive = false;

// --------------------------------------------------------------------------------
// FUNÇÕES HUFFMAN
// --------------------------------------------------------------------------------
String huffmanCompress(const String &data) {
  String compressed;
  for (char c : data) {
    auto it = huffmanCodes.find(c);
    if (it != huffmanCodes.end()) {
      compressed += it->second;
    } else {
      compressed += "110101"; // Caractere desconhecido (espaço como fallback)
    }
  }
  return compressed;
}

String binaryToBase64(const String &binary) {
  const char* base64_chars = "ABCDEFGHIJKLMNOPQRSTUVWXYZabcdefghijklmnopqrstuvwxyz0123456789+/";
  String result;
  
  // Cria uma cópia modificável do input
  String paddedBinary = binary;
  Serial.printf("\n[DEBUG] TAMANHO DO CODIGO BINARIO: %s\n", String(paddedBinary.length()).c_str());
  int len = paddedBinary.length();
  
  // Preencher com zeros se necessário
  while (len % 6 != 0) {
    paddedBinary += '0';
    len++;
  }

  int i = 0;
  while (i < len) {
    int val = 0;
    for (int j = 0; j < 6; j++) {
      val <<= 1;
      if (paddedBinary[i+j] == '1') val |= 1;
    }
    i += 6;
    
    result += base64_chars[val];
  }

  // // Ajustar padding ANTIGO
  // int pad = (6 - (binary.length() % 6)) % 6;
  // for (int p = 0; p < pad/2; p++) {
  //   result += '=';
  // }

  // Ajustar padding NOVO
  while (result.length() % 4 != 0) {
    result += '=';
  }
  // Serial.printf("\n[DEBUG] O PAD DO CODIGO EM BASE64: %s\n", String(pad).c_str());
  Serial.printf("\n[DEBUG] TAMANHO DO CODIGO EM BASE64 %s\n", String(result.length()).c_str());
  Serial.printf("\n[DEBUG] CODIGO EM BASE64 %s\n", result.c_str());
  return result;
}


void testHuffman() {
  String test = "{\"temperatura_interna\":25.50}";
  String compressed = huffmanCompress(test);
  String encoded = binaryToBase64(compressed);
  
  Serial.println("\n[TESTE] Original: " + test);
  Serial.println("[TESTE] Compactado: " + compressed);
  Serial.println("[TESTE] Base64: " + encoded);
  Serial.println("[TESTE] Tamanho original: " + String(test.length()) + " bytes");
  Serial.println("[TESTE] Tamanho compactado: " + String(encoded.length()) + " bytes\n");
}

// --------------------------------------------------------------------------------
// SETUP
// --------------------------------------------------------------------------------
void setup() {
  Serial.begin(115200);
  Serial.println("[DEBUG] Iniciando setup...");

  pinMode(LED_OK_PIN, OUTPUT);
  pinMode(LED_ALERT_PIN, OUTPUT);
  pinMode(TRIG_PIN, OUTPUT);
  pinMode(ECHO_PIN, INPUT);

  dht_in.begin();
  dht_ext.begin();
  Serial.println("[DEBUG] Sensores DHT inicializados.");

  Serial.println("[DEBUG] Inicializando PN532...");
  nfc.begin();
  uint32_t version = nfc.getFirmwareVersion();
  if (version) { 
    nfc.SAMConfig(); 
    Serial.println("[DEBUG] PN532 OK."); 
  } else { 
    Serial.println("[ERROR] PN532 não detectado!"); 
  }

  lcd.begin(20, 4);
  lcd.clear();
  lcd.print("Iniciando...");
  Serial.println("[DEBUG] LCD inicializado.");

  setup_wifi();

  espClient.setCACert(hivemq_root_ca);
  client.setServer(mqtt_server, mqtt_port);
  client.setCallback(callback);
  Serial.println("[DEBUG] MQTT TLS configurado.");

  testHuffman();
  Serial.println("[DEBUG] Setup concluído!!!");
}

// --------------------------------------------------------------------------------
// LOOP
// --------------------------------------------------------------------------------
void loop() {
  if (!client.connected()) reconnect_mqtt();
  client.loop();

  atualizarTempHistory();
  verificarRFID();
  atualizarDoorState();
  checarEventos();
  atualizarLCD();

  unsigned long now = millis();
  if (now - lastPeriodicSend >= PERIODIC_SEND_INTERVAL) {
    lastPeriodicSend = now;
    enviarDados("periodic");
  }

  if (!alarmState && now - lastGreenBlink >= GREEN_BLINK_INTERVAL) {
    lastGreenBlink = now; 
    blinkLED(LED_OK_PIN, 100);
  }
  if (alarmState && now - lastRedBlink >= RED_BLINK_INTERVAL) {
    lastRedBlink = now; 
    blinkLED(LED_ALERT_PIN, 100);
  }
}


// --------------------------------------------------------------------------------
// FUNÇÕES AUXILIARES
// --------------------------------------------------------------------------------

// Conecta ao Wi‑Fi e imprime debug
static void setup_wifi() {
  Serial.print("[DEBUG] Conectando ao Wi‑Fi ");
  WiFi.begin(ssid, password);
  while (WiFi.status() != WL_CONNECTED) {
    delay(500);
    Serial.print(".");
  }
  Serial.printf("\n[DEBUG] Wi‑Fi conectado: %s\n", WiFi.localIP().toString().c_str());
}

// Reconecta ao broker MQTT
static void reconnect_mqtt() {
  while (!client.connected()) {
    // Serial.println("[DEBUG] Tentando conexão MQTT...");
    if (client.connect("ESP32_Client", mqtt_username, mqtt_password)) {
      // Serial.println("[DEBUG] Conectado ao MQTT.");
      client.subscribe(control_topic);
      // Serial.printf("[DEBUG] Inscrito em: %s\n", control_topic);
    } else {
      Serial.printf("[ERROR] Falha MQTT, rc=%d. Tentando em 5s\n", client.state());
      delay(5000);
    }
  }
}

// Pisca um LED por 'duration' ms
static void blinkLED(uint8_t pin, int duration) {
  digitalWrite(pin, HIGH);
  delay(duration);
  digitalWrite(pin, LOW);
}

// Atualiza os LEDs de status
static void atualizarLEDs() {
  digitalWrite(LED_ALERT_PIN, alarmState ? HIGH : LOW);
  digitalWrite(LED_OK_PIN,    alarmState ? LOW  : HIGH);
}

// Mede distância ultrassônica
static float medirDistancia() {
  digitalWrite(TRIG_PIN, LOW);  delayMicroseconds(2);
  digitalWrite(TRIG_PIN, HIGH); delayMicroseconds(10);
  digitalWrite(TRIG_PIN, LOW);
  long dur = pulseIn(ECHO_PIN, HIGH);
  return (dur * 0.034) / 2.0;
}

void atualizarTempHistory() {
  float t = dht_in.readTemperature();
  tempHistory[tempIndex] = t;
  tempIndex = (tempIndex + 1) % TEMP_HISTORY_SIZE;
  // Serial.printf("[DEBUG] Temp interna lida: %.2f°C\n", t);

  if (TEMP_HISTORY_SIZE >= 10) {
    float s5 = t, s10 = t;
    for (int i = 1; i < 5; i++) s5  += tempHistory[(tempIndex - i + TEMP_HISTORY_SIZE) % TEMP_HISTORY_SIZE];
    for (int i = 1; i < 10; i++) s10 += tempHistory[(tempIndex - i + TEMP_HISTORY_SIZE) % TEMP_HISTORY_SIZE];
    if (s5/5.0 > s10/10.0 && !avgAlertActive) {
      avgAlertActive = true;
      Serial.println("[DEBUG] Alerta média ativado.");
      enviarDados("avg_temp_alert");
    } else if (s5/5.0 <= s10/10.0 && avgAlertActive) {
      avgAlertActive = false;
      Serial.println("[DEBUG] Média estabilizada.");
      enviarDados("avg_temp_stable");
    }
  }
}

void atualizarLCD() {
  float ti = dht_in.readTemperature();
  float te = dht_ext.readTemperature();
  float he = dht_ext.readHumidity();
  lcd.clear();
  lcd.setCursor(0,0);
  lcd.printf("Int:%.1fC Ext:%.1fC", ti, te);
  lcd.setCursor(0,1);
  lcd.printf("Porta:%s", doorOpen ? "Aberta" : "Fechada");
  lcd.setCursor(0,2);
  lcd.printf("Umid Ext:%.1f%%", he);
  lcd.setCursor(0,3);
  lcd.printf("Stat:%s", alarmState ? "ALERT" : "OK");
}

void verificarRFID() {
  uint8_t success = nfc.inListPassiveTarget();
  if (success) {
    uint8_t uid[7], len;
    if (nfc.readPassiveTargetID(PN532_MIFARE_ISO14443A, uid, &len)) {
      String u;
      for (int i = 0; i < len; i++) {
        u += String(uid[i], HEX);
      }
      if (u != usuarioAtual) {
        usuarioAtual = u;
        lastRFIDTime = millis();
        Serial.printf("[DEBUG] Novo RFID: %s\n", usuarioAtual.c_str());
        if (doorOpen) {
          Serial.println("[DEBUG] Porta aberta com RFID, enviando rfid_door.");
          enviarDados("rfid_door");
        }
      }
    }
  }
}

void atualizarDoorState() {
  float dist = medirDistancia();
  bool nowOpen = dist > distancia_limite;
  // Serial.printf("[DEBUG] Distância lida: %.2f cm\n", dist);
  if (nowOpen != doorOpen) {
    doorOpen = nowOpen;
    if (doorOpen) {
      Serial.println("[DEBUG] Porta abriu.");
      if (millis() - lastRFIDTime > UNAUTH_WINDOW_BEFORE) {
        Serial.println("[DEBUG] Porta não autorizada, enviando unauthorized_door.");
        alarmState = true;
        enviarDados("unauthorized_door");
      }
    } else {
      Serial.println("[DEBUG] Porta fechou.");
      alarmState = false;
    }
  }
}

void checarEventos() {
  float t = dht_in.readTemperature();
  if (t > THRESHOLD_TEMP) {
    if (tempAboveStart == 0) {
      tempAboveStart = millis();
      Serial.println("[DEBUG] Temperatura acima do limiar, iniciando contador.");
    } else if (millis() - tempAboveStart >= TEMP_ALERT_DURATION) {
      Serial.println("[DEBUG] Temperatura alta por 10s, enviando temp_high.");
      alarmState = true;
      enviarDados("temp_high");
    }
  } else {
    tempAboveStart = 0;
  }
}

void enviarDados(String motivo) {
  Serial.printf("[DEBUG] Montando payload para motivo: %s\n", motivo.c_str());
  
  // Ler dados dos sensores
  float ti = dht_in.readTemperature();
  float hi = dht_in.readHumidity();
  float te = dht_ext.readTemperature();
  float he = dht_ext.readHumidity();
  String portState = (medirDistancia() <= distancia_limite) ? "Fechada" : "Aberta";

  // Construir payload JSON original
  String payload = "{";
  payload += "\"temperatura_interna\":" + String(ti, 2) + ",";
  payload += "\"umidade_interna\":"   + String(hi, 2) + ",";
  payload += "\"temperatura_externa\":" + String(te, 2) + ",";
  payload += "\"umidade_externa\":"   + String(he, 2) + ",";
  payload += "\"estado_porta\":\""     + portState + "\",";
  payload += "\"usuario\":\""          + usuarioAtual + "\",";
  payload += "\"alarm_state\":\""      + String(alarmState ? "ALERT" : "OK") + "\",";
  payload += "\"motivo\":\""           + motivo + "\"}";

  // Compactar e codificar
  String compressed = huffmanCompress(payload);
  String encoded = binaryToBase64(compressed);
  
  // Construir payload final
  String finalPayload = "{";
  finalPayload += "\"huffman\":\"" + encoded + "\",";
  finalPayload += "\"dict\":\"" + HUFFMAN_DICT_VERSION + "\",";
  finalPayload += "\"length\":" + String(compressed.length()) + "}";

  // Publicar
  bool ok = client.publish(mqtt_topic.c_str(), finalPayload.c_str());
  
  // Logs detalhados
  Serial.println("Payload original: " + payload);
  Serial.println("Tamanho original: " + String(payload.length()) + " bytes");
  Serial.println("Payload compactado: " + finalPayload);
  Serial.println("Tamanho compactado: " + String(finalPayload.length()) + " bytes");
  Serial.printf("[DEBUG] Publicação %s\n", ok ? "OK" : "FALHA");
}

// Callback modificado para lidar com possíveis comandos
void callback(char* topic, byte* payload, unsigned int length) {
  String msg;
  for (unsigned int i = 0; i < length; i++) {
    msg += (char)payload[i];
  }
  
  Serial.println("[DEBUG] Mensagem recebida: " + msg);
  
  // Comando para atualizar threshold
  if (msg.startsWith("SET_THRESHOLD:")) {
    float newThreshold = msg.substring(14).toFloat();
    THRESHOLD_TEMP = newThreshold;
    Serial.println("[DEBUG] Novo threshold definido: " + String(THRESHOLD_TEMP));
  }
}

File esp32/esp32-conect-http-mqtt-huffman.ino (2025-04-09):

#include <WiFi.h>
#include <WiFiClientSecure.h>
#include <PubSubClient.h>
#include <DHT.h>
#include <SPI.h>
#include <time.h>
#include <Adafruit_PN532.h>
#include <LiquidCrystal.h>

// Para Huffman:
#include <map>
#include <queue>

// ----- IMPLEMENTAÇÃO DO HUFFMAN -----
struct HuffmanNode {
  char ch;
  int freq;
  HuffmanNode *left;
  HuffmanNode *right;
  HuffmanNode(char _ch, int _freq) : ch(_ch), freq(_freq), left(NULL), right(NULL) {}
};

struct CompareNode {
  bool operator()(HuffmanNode* const & n1, HuffmanNode* const & n2) {
    return n1->freq > n2->freq;
  }
};

HuffmanNode* huffmanTree = NULL;
std::map<char, String> huffmanCodes;

void buildHuffmanCodes(HuffmanNode* root, String code) {
  if (!root) return;
  if (root->left == NULL && root->right == NULL) {
    huffmanCodes[root->ch] = code;
  }
  buildHuffmanCodes(root->left, code + "0");
  buildHuffmanCodes(root->right, code + "1");
}

HuffmanNode* buildHuffmanTree(const String &data) {
  std::map<char, int> freq;
  for (int i = 0; i < data.length(); i++) {
    freq[data[i]]++;
  }
  std::priority_queue<HuffmanNode*, std::vector<HuffmanNode*>, CompareNode> pq;
  for (auto pair : freq) {
    pq.push(new HuffmanNode(pair.first, pair.second));
  }
  while (pq.size() > 1) {
    HuffmanNode* left = pq.top(); pq.pop();
    HuffmanNode* right = pq.top(); pq.pop();
    HuffmanNode* merged = new HuffmanNode('\0', left->freq + right->freq);
    merged->left = left;
    merged->right = right;
    pq.push(merged);
  }
  return pq.top();
}

String huffmanCompress(const String &data) {
  String compressed = "";
  for (int i = 0; i < data.length(); i++) {
    compressed += huffmanCodes[data[i]];
  }
  return compressed;
}

String huffmanDecompress(const String &compressed, HuffmanNode* root) {
  String decompressed = "";
  HuffmanNode* curr = root;
  for (int i = 0; i < compressed.length(); i++) {
    if (compressed[i] == '0')
      curr = curr->left;
    else
      curr = curr->right;
    if (!curr->left && !curr->right) {
      decompressed += curr->ch;
      curr = root;
    }
  }
  return decompressed;
}

// ----- FIM DO HUFFMAN -----


// --------------------------------------------------------------------------------
// Definições de pinos e constantes do projeto
// --------------------------------------------------------------------------------

// Sensor DHT interno (container) 
#define DHT_PIN_IN 4
#define DHT_TYPE   DHT11 
DHT dht_in(DHT_PIN_IN, DHT_TYPE);

// Sensor DHT externo (sala)
#define DHT_PIN_EXT 14
DHT dht_ext(DHT_PIN_EXT, DHT_TYPE);

// Sensor ultrassônico
#define TRIG_PIN 5
#define ECHO_PIN 25

// LEDs de status
#define LED_OK_PIN    2   // LED Verde (status normal)
#define LED_ALERT_PIN 15  // LED Vermelho (alerta)

// Módulo PN532 (RFID)
#define SDA_PIN 21
#define SCL_PIN 22
Adafruit_PN532 nfc(SDA_PIN, SCL_PIN);

// Configuração do LCD 16x4 (pinos de exemplo)
#define LCD_RS 26
#define LCD_E  27
#define LCD_D4 33
#define LCD_D5 32
#define LCD_D6 35
#define LCD_D7 34
LiquidCrystal lcd(LCD_RS, LCD_E, LCD_D4, LCD_D5, LCD_D6, LCD_D7);

// Limites e variáveis de temperatura (container)
#define TEMP_MIN 2.0
#define TEMP_MAX 8.0
float THRESHOLD_TEMP = 9.0;       // Limite para alerta de alta temperatura
unsigned long tempAboveStart = 0; // Tempo em que a temperatura ficou acima do limiar

// Intervalos de tempo (milissegundos)
const unsigned long PERIODIC_SEND_INTERVAL = 60000;    // 1 minuto
const unsigned long GREEN_BLINK_INTERVAL   = 5000;     // LED verde: 5s
const unsigned long RED_BLINK_INTERVAL     = 1000;     // LED vermelho: 1s
const unsigned long UNAUTH_WINDOW_BEFORE   = 60000;     // 1 minuto antes
const unsigned long UNAUTH_WINDOW_AFTER    = 15000;     // 15 segundos depois
const unsigned long TEMP_ALERT_DURATION    = 10000;     // 10s de alta temperatura

// Distância para considerar porta fechada
const float distancia_limite = 10.0;

// MQTT: Tópicos – configurados via variáveis para facilitar alteração
String centro    = "centroDeVacinaXYZ";
String container = "containerXYZ";
String mqtt_topic = "/" + centro + "/" + container;  // Ex: /centroDeVacinaXYZ/containerXYZ

// Tópico de controle para receber comandos remotos (ex.: mudança de tópico)
const char* control_topic = "esp32/control";

// Configurações da rede Wi-Fi
const char* ssid     = "Starlink_CIT";
const char* password = "Ufrr@2024Cit";

// Configurações do HiveMQ (broker MQTT)
const char* mqtt_server   = "cd8839ea5ec5423da3aaa6691e5183a5.s1.eu.hivemq.cloud";
const int   mqtt_port     = 8883;
const char* mqtt_username = "hivemq.webclient.1734636778463";
const char* mqtt_password = "EU<pO3F7x?S%wLk4#5ib";

// Objetos de rede e MQTT
WiFiClientSecure espClient;
PubSubClient client(espClient);

// Variáveis globais de controle
unsigned long lastPeriodicSend = 0;
unsigned long lastGreenBlink   = 0;
unsigned long lastRedBlink     = 0;

String usuarioAtual = "desconhecido";
bool doorOpen       = false;
bool alarmState     = false;

unsigned long doorOpenTime = 0;  // Tempo em que a porta foi aberta
unsigned long lastRFIDTime = 0;  // Última leitura de RFID

// Histórico de temperaturas (sensor interno) – últimos 10 valores
#define TEMP_HISTORY_SIZE 10
float tempHistory[TEMP_HISTORY_SIZE] = {0};
int tempIndex = 0;
bool avgAlertActive = false; // Indica se alerta de média está ativo

// ----- Variáveis globais do Huffman -----
// Usaremos um dicionário estático construído a partir de um sample representativo dos caracteres do payload.
String sampleAlphabet = "{\"temperatura_interna\": 0.00,\"umidade_interna\": 0.00,\"temperatura_externa\": 0.00,\"umidade_externa\": 0.00,\"estado_porta\": \"Fechada\",\"usuario\": \"desconhecido\",\"alarm_state\": \"OK\",\"motivo\": \"periodic\"}";
 
// ----- SETUP ----- 
void setup() {
  Serial.begin(115200);

  // Configura LEDs
  pinMode(LED_OK_PIN, OUTPUT);
  pinMode(LED_ALERT_PIN, OUTPUT);

  // Configura sensor ultrassônico
  pinMode(TRIG_PIN, OUTPUT);
  pinMode(ECHO_PIN, INPUT);

  // Inicializa sensores DHT
  dht_in.begin();
  dht_ext.begin();

  // Inicializa módulo PN532 (RFID)
  Serial.println("Inicializando PN532...");
  nfc.begin();
  uint32_t versiondata = nfc.getFirmwareVersion();
  if (versiondata) {
    nfc.SAMConfig();
    Serial.println("PN532 inicializado com sucesso.");
  } else {
    Serial.println("Módulo PN532 não detectado.");
  }

  // Inicializa display LCD
  lcd.begin(16, 4);
  lcd.clear();
  lcd.print("Iniciando...");

  // Conexão Wi-Fi
  setup_wifi();

  // Configura MQTT
  espClient.setInsecure();
  client.setServer(mqtt_server, mqtt_port);
  client.setCallback(callback);

  // ----- Constrói a árvore Huffman e o dicionário estático -----
  huffmanTree = buildHuffmanTree(sampleAlphabet);
  buildHuffmanCodes(huffmanTree, "");
  
  Serial.println("Dicionário Huffman construído:");
  for (auto pair : huffmanCodes) {
    Serial.print(pair.first);
    Serial.print(": ");
    Serial.println(pair.second);
  }
}
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

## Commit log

2025-03-29 chore(esps): att para refletir novas funções
    changelog:
    - suporte inicial à http para servidor flask
    - add 2 leds para indicação de estado atual do sistema
    - add de motor para gerenciar acesso
2025-04-01 feat(docs): novo documento de requisitos
2025-04-01 feat(docs): fluxo de dados da aplicação
    Closes #4
2025-04-01 feat(docs): documento de plano de testes atualizado
    Closes #6
2025-04-01 chore(docs): att esquema de conexao Closes #9
2025-04-01 chore(docs): att esquema de conexao
    Closes #9
2025-04-01 chore(docs): att com dois dhts e sensor ultrasonico
    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
2025-04-04 chore(eps): limpeza de comentarios
2025-04-06 chore(esp32): atts no código
    Closes #10
    Changelog:
    - modificação de lógicva do sensor PIR para sensor Ultrassônico
    - remoção do motor de passo do projeto
    - adição de callback para mudar tópico do projeto
2025-04-07 chore(esp): algoritmo de huffman
    Closes #11, implemente de forma separada do código original para evitar falhas, vamos mexer no código posteriormente
2025-04-07 chore(esp): implementação do algoritmo de huffman
    closes #11
2025-04-08 chore(esp): imp. de criptografia AES
    Closes #12
2025-04-08 chore(docs): documentação de estruturas compac. e encript
2025-04-08 chore(esp): atualização de pinagem
2025-04-09 chore(esp): desacoplamento de código para facilitar leitura
    ajuda na velocidade de compilação e processamento dos dados também.
2025-04-12 chore: reacoplamento do código devido arduino IDE n suportar desacoplamento
2025-04-12 debug(esp): removendo prints de debug pois está correto
2025-04-18 chore(docs): att Fluxograma de Dados SafeVax
    Closes #30
2025-04-18 chore(docs): att do documento de testes e documento de requisitos
    Closes #26
    Closes #27
2025-04-18 chore(docs): att documento de requisitos
2025-04-19 chore(esp): assinatura de certificados TLS com MQTT
2025-04-19 chore(3d): base da caixa do protótipo
    [Base_Safevax_imprimir.stl]
2025-04-19 chore(esp32): compactação via huffman ok
2025-04-20 chore(deploy): preparando ambiente para deploy 1
2025-04-20 chore(flask): atualização de nomenclatura + decodificação de huffman
2025-04-20 chore(flask): huffman com novo dicionário com resolução de prefixos
2025-04-20 chore(flask): adicionei reposição de requisição enquanto n resolvemos o problema do huffman depack
2025-04-21 chore(docs): add folder de imagens do projeto
2025-04-21 chore(3d): topo da caixa do protótipo
    [Topo_Safevax_imprimir.stl]
2025-04-22 fix(flask): validação de certificados online
2025-04-22 chore(huffman): modificação no algoritmo de padding
2025-04-23 chore(esp): fix printf errado na variavel pad
    [esp32-conect-TLS.ino]
2025-04-24 chore(esp32): payload de dados funcional
2025-04-25 chore(3d): otimização no tempo de impressão
    [Topo_Safevax_imprimir.stl]
2025-04-25 chore(3d): suporte para o sensor ultrassônico
    [Sensor-ultrassonico_Safevax_imprimir.stl]
2025-04-25 chore(3d): suporte para o sensor de temp e umidade
    [DHT_Interno_imprimir.stl]
2025-04-25 chore(3d): adicionais cosméticos
    [Letras_Caixa_imprimir.stl]
2025-04-25 chore(flask): melhoria nas mensagens de debugging
2025-04-25 chore(streamlit): instalação automática de bibliotecas
2025-04-25 chore(streamlit): atualização automática de bibliotecas
2025-04-25 chore(docs): att dos slides de apresentacao Safevax podendo ser atualizado até as 16h de 25/04/25
    Closes #18
2025-04-25 chore(docs): att de slide
